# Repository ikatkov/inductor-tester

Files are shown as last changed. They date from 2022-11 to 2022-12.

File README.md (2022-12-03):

# (Power) Inductor saturation current tester

~60A max current. Power supply 5-25V.
Based on http://elm-chan.org/works/lchk/report.html

You will need an oscilloscope to take measurements.

# Theory

Once powered, the capacitor bank charges up. The circuit fires off a variable-width pulse into the MOSFET gate. MOSFET turns ON and short-circuits the inductor to the capacitor power bank. The current starts to rise linearly until the saturation point is reached. Once the inductor is saturated, it behaves like an ohmic piece of wire, and the current increases exponentially until the pulse is over, and the MOSFET is switched OFF. Saturation is a knee, not a sharp point. So you have some wiggle room in what current you designate as a "saturation current." Before the saturation point and including the "knee region," inductance will be higher than labeled. Once saturated sufficiently - inductance will drop.

This is how a regular plot should look like

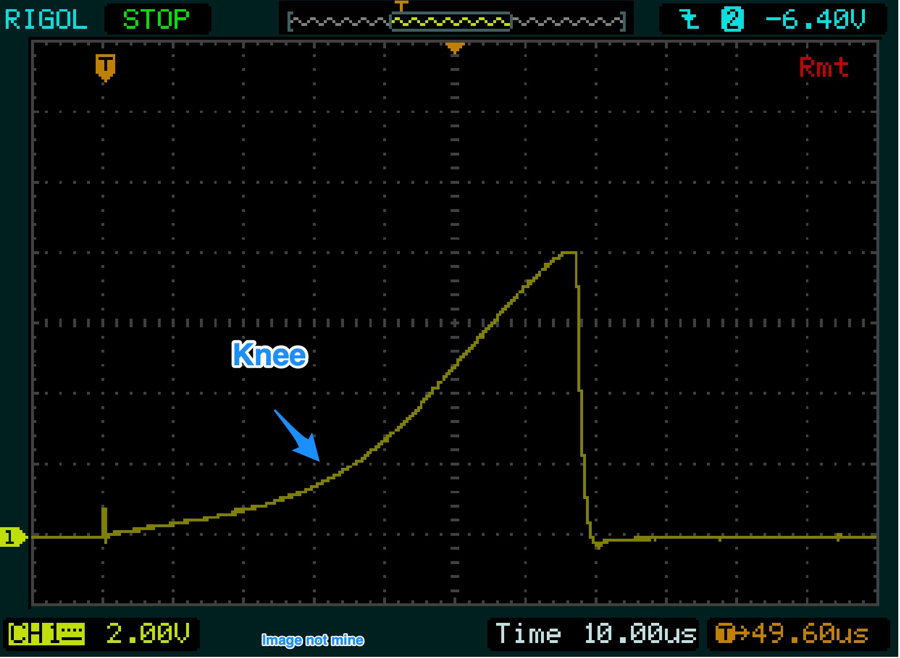
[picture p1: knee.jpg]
Knee


This is how oversaturation, should look like

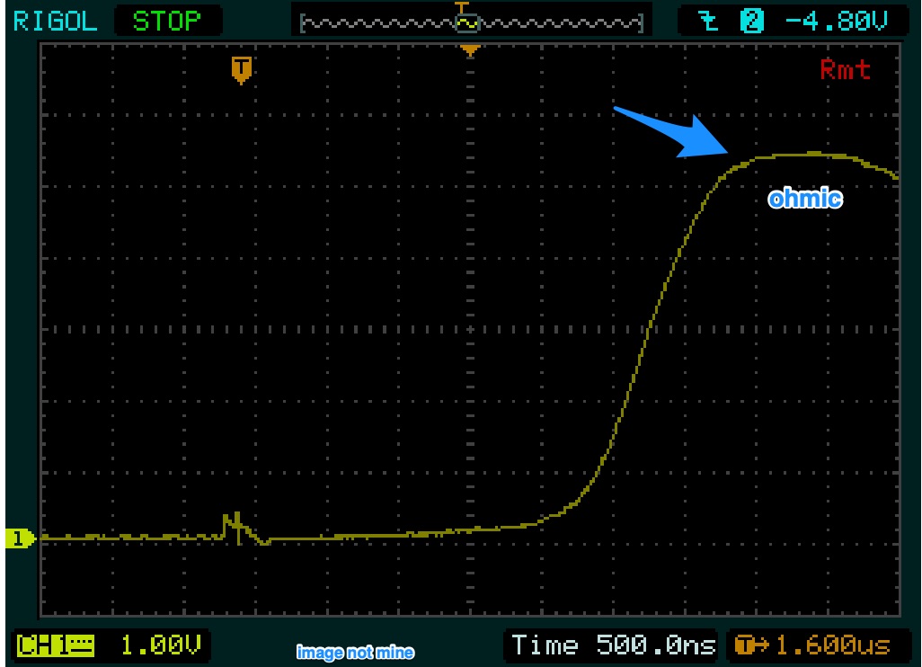
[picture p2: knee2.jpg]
Oversaturation


Commercial manufacturers pick the point where a power inductor loses 20-30% of its labeled inductance. One can safely operate inductors at x1.3-1.5 their knee point.

You take voltage drop measurements across 0.1 Ohm resistor, multiply by 10 and get current in Amps flowing through your inductor under test. `I = V*10`

You can also compute actual inductance be taking your supply voltage and dividing by the voltage slope. 
`L = Vs * Δt / ΔI`. 

# Practical operations

See "sort-of" instructions video https://www.youtube.com/watch?v=3Y_WcuIenSM
Notice that although their PCB is labeled 1us..50us. It's impossible to get a positive pulse width of less than 10uS with NE555. One can replace it with other astable timers ICs, but you need a separate MOSFET driving circuitry. NE555 raising and falling times ~350ns, with a max current of 200mA, which is not enough to quickly switch power MOSFETs ON/OFF. The MOSFET will be in its linear region for some time. Therefore the trigger pulse is set to ~50Hz, letting MOSFET cool down between pulses. Also, notice that the current sense shunt, capacitor bank ESR and traces resistance limits max current to ~56A.
You would want to rig some sort of replacable solder-pads on the top of the PCB, so you can finger-press small SMD inductors to it and solder large ones to take measurements. There are header holes for this.

* Unplug the power
* Turn the potentiometer all the way counterclockwise. Set the duration selector jumper to the shortest range. 
* Connect oscilloscope probes
* Plug the power
* Look at the oscilloscope
* Turn the potentiometer clockwise (increasing the pulse width) until you see the saturation knee
* If you still see a linear ramp, unplug, change the duration selector jumper to the next position, turn the potentiometer all the way counterclockwise and repeat
* Take measurements

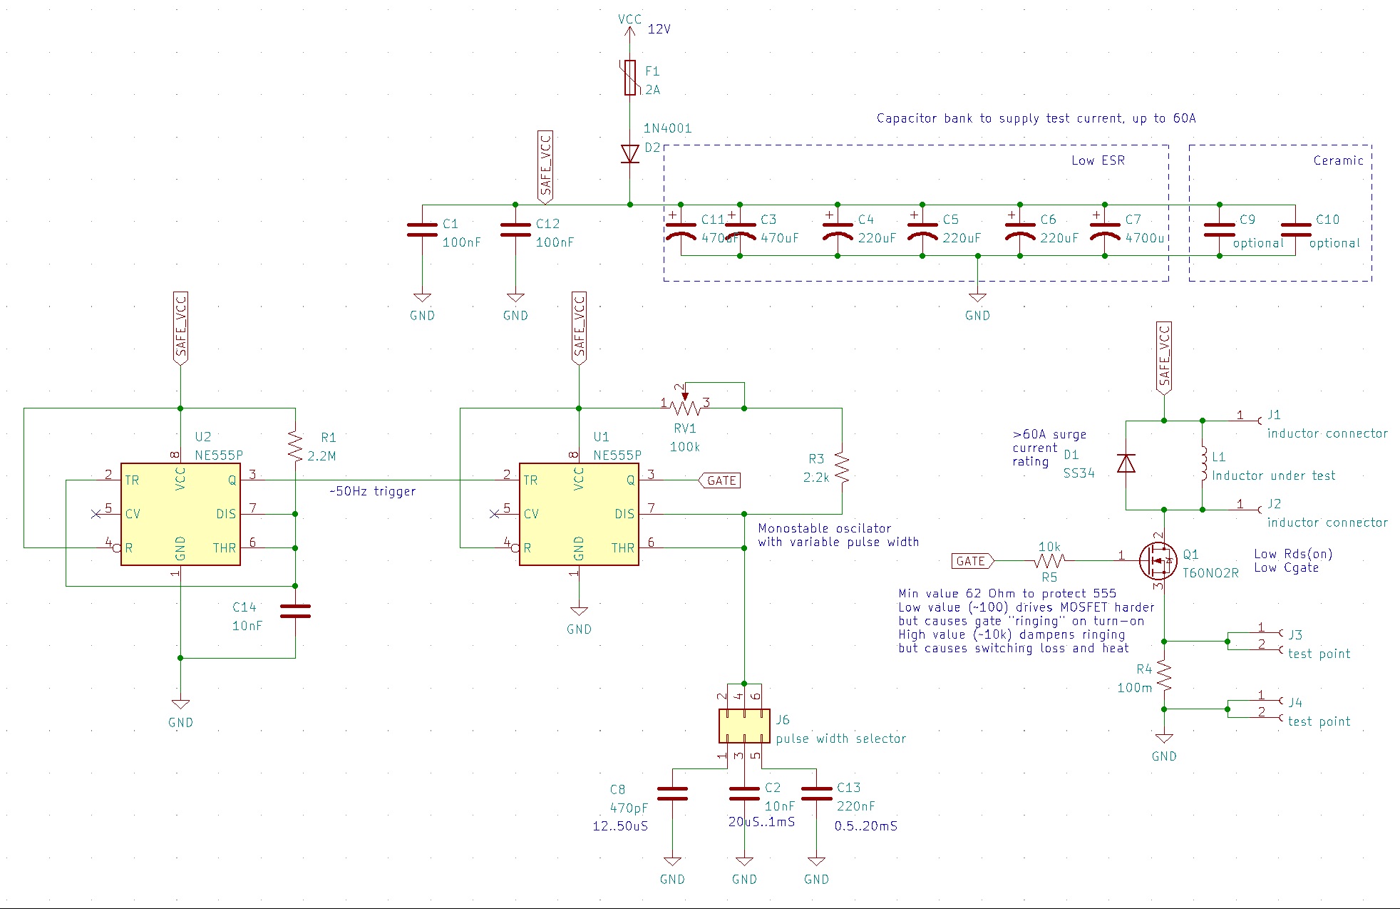
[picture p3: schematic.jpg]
Schematic


# Manufacturing

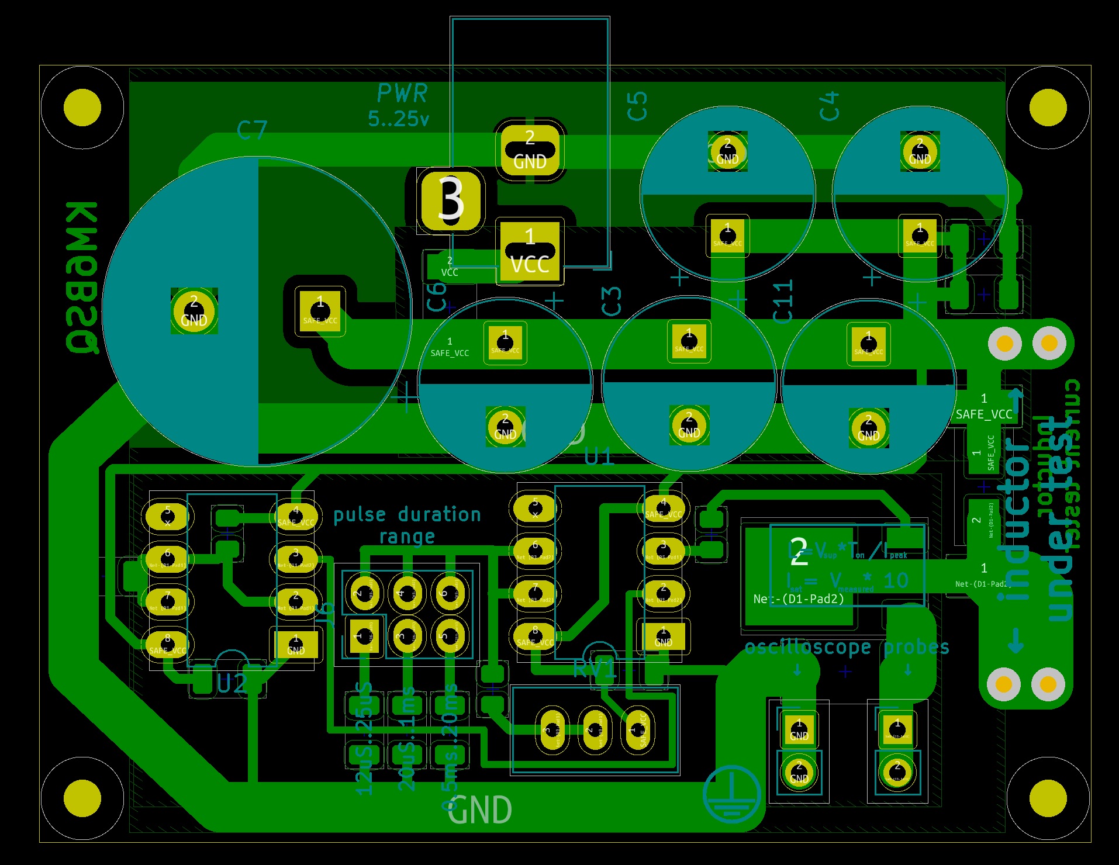
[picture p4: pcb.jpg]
PCB

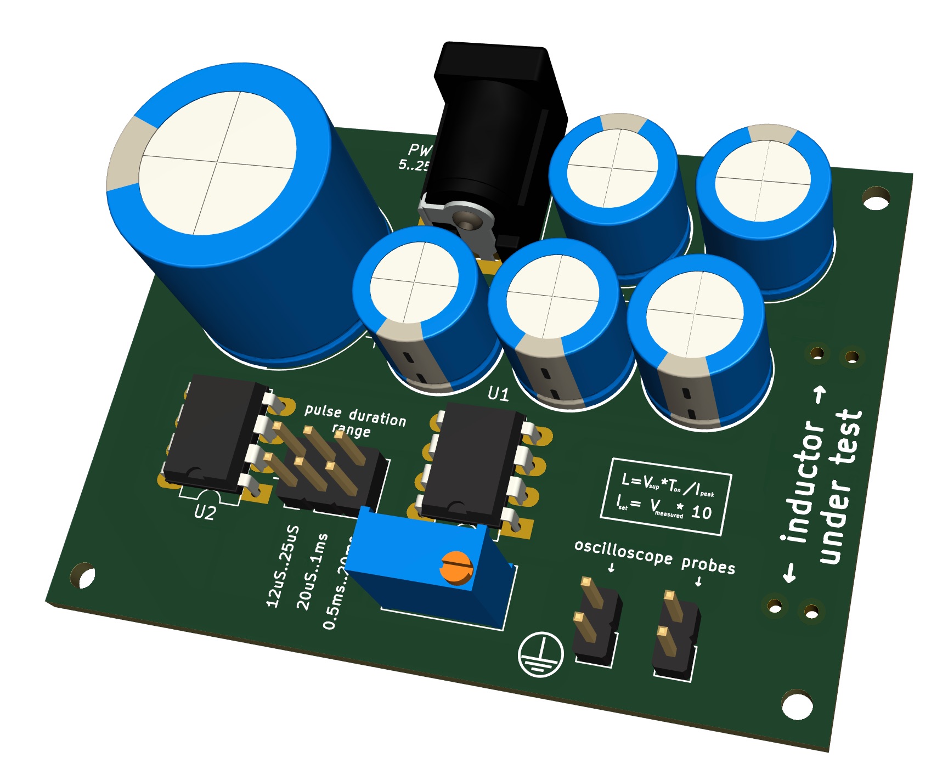
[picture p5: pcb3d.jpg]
Top view


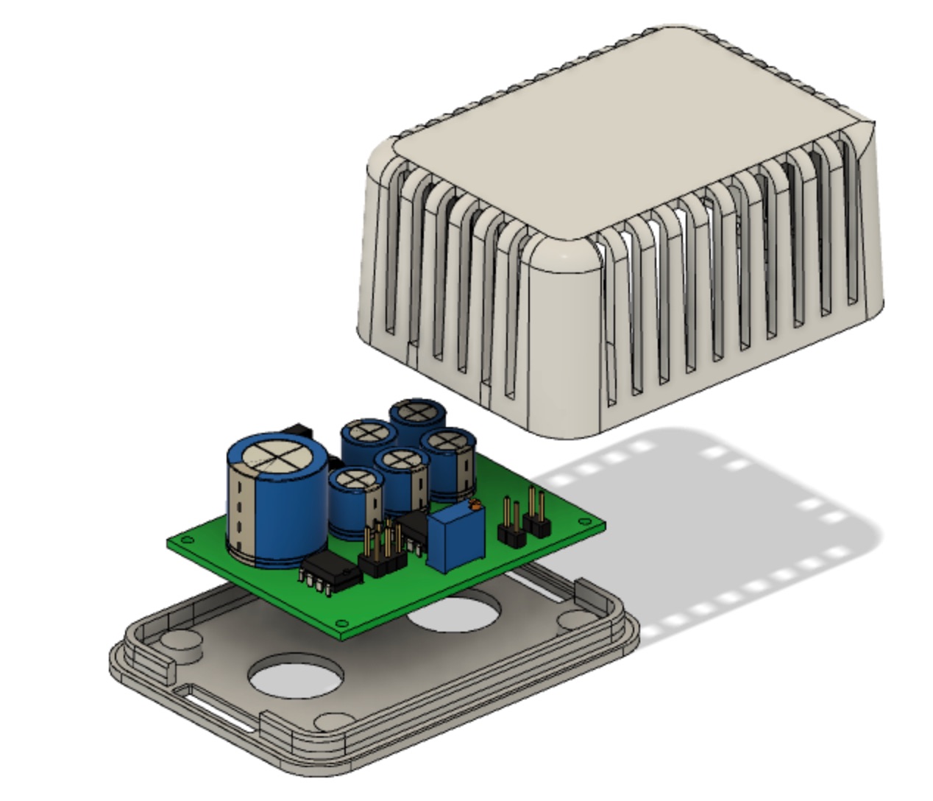
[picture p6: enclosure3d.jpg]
Enclosure


[PCB STEP model](main.step)

[Full STEP model](enclosure.step)

[Full Fusion360 model](enclosure.f3zki)

[PCB Thermal Heat Flow Analysis](heat.jpg)

# Future improvements

NE555 is a compromise for this project purpose, you need two of them to deliver a short pulse, but it can also source 200ma current by itself. An alternative design is to use a cheap MCU and a MOSFET driver. Same PCB footprint, but better timing (no need to mess around with jumpers) and higher currents to turn the MOSFET on and off. High gate current also means "ringing" 
on MOSFET turn on, which in turn manifests itself as current measurements ringing. For large inductors it is OK, for small (SMD) it might be hard to take measurements. With a better MCU one can even do automatic pulse control. This gets complex fast. 16 MHz Arduino is ~ 100uS per ADC sample. 

`For a 16 MHz Arduino the ADC clock is set to 16 MHz/128 = 125 KHz. Each conversion in AVR takes 13 ADC clocks so 125 KHz /13 = 9615 Hz.`

As soon as you consider a fast external ADC, you start worry about crystal clock-jitter, temperature drift and SPI speed.

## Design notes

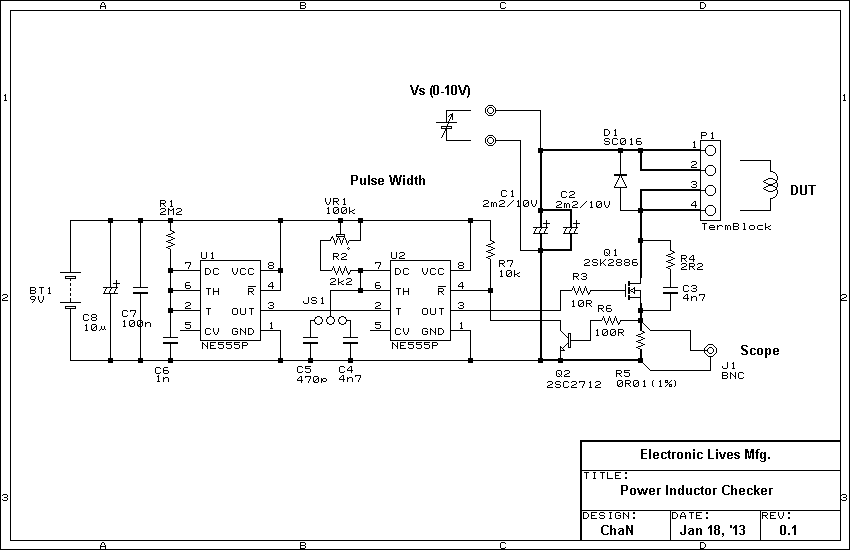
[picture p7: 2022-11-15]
original-lchk_schematic.png

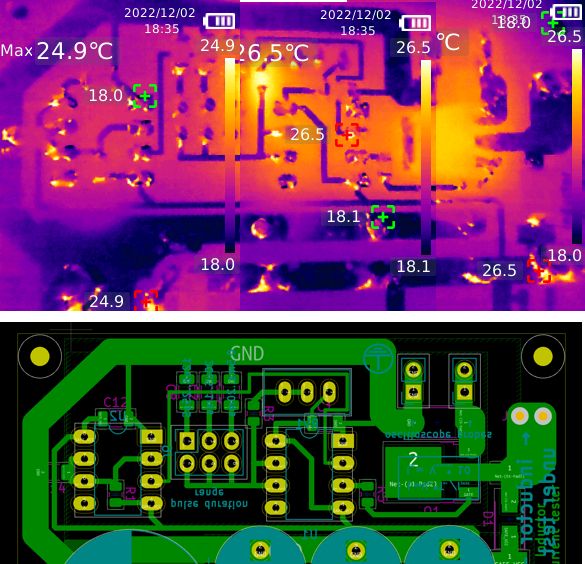
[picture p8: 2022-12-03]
heat.jpg

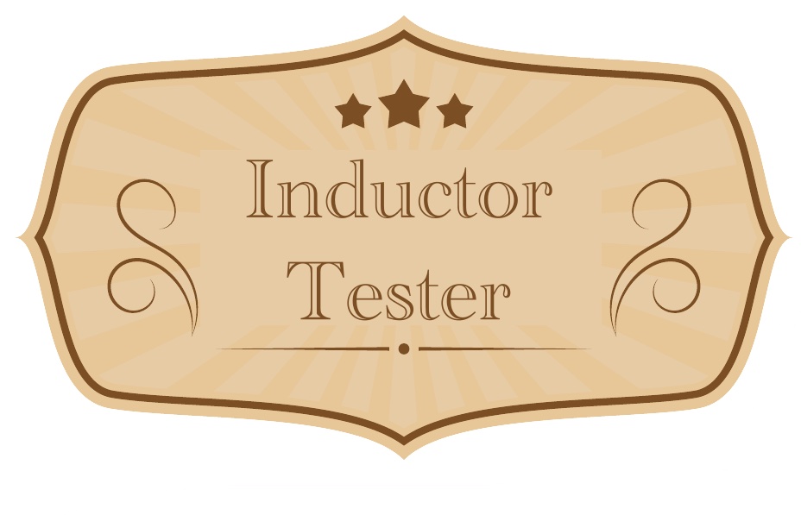
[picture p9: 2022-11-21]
label.jpg

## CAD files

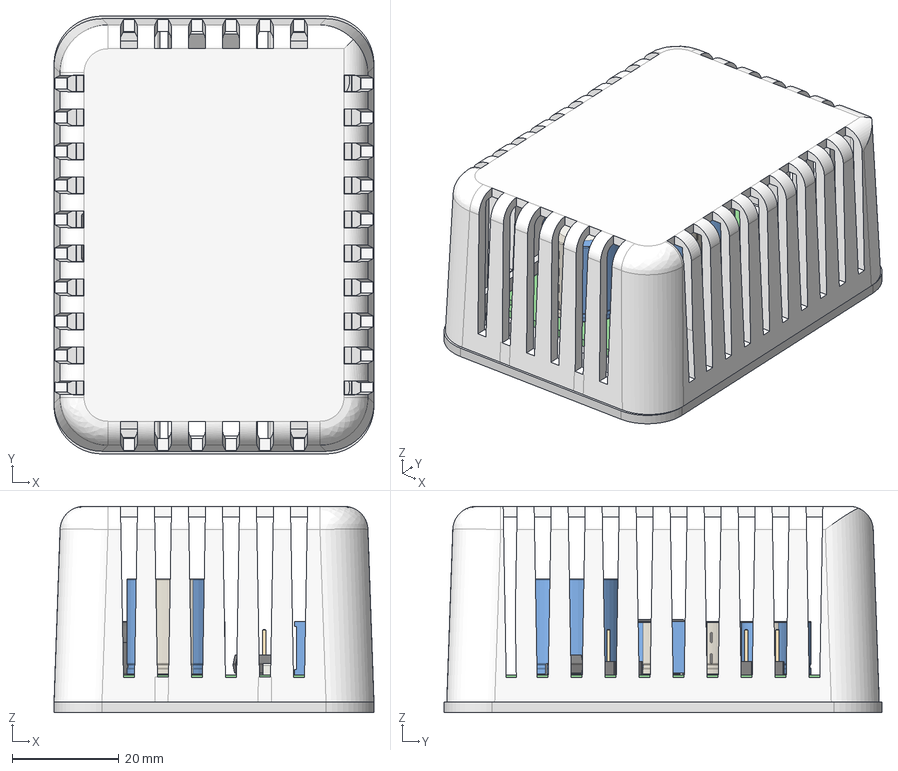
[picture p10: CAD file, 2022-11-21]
enclosure.step
60.0 x 82.1 x 38.7 mm
1551V1 BOT2
1551V1 TOP1
main PCB

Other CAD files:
enclosure.f3z

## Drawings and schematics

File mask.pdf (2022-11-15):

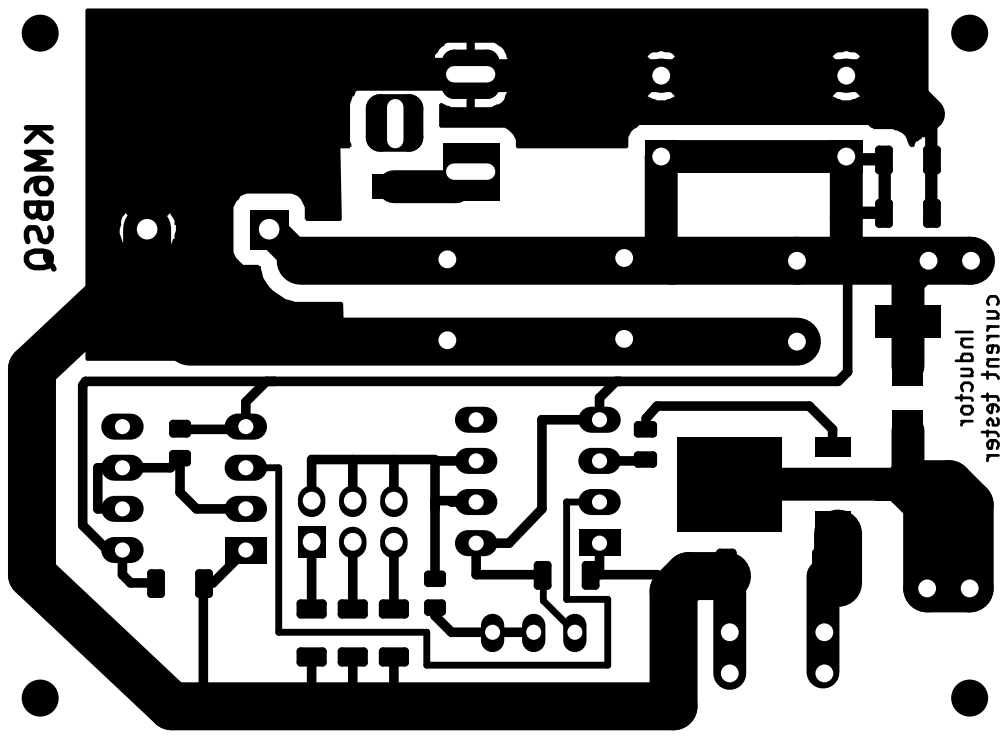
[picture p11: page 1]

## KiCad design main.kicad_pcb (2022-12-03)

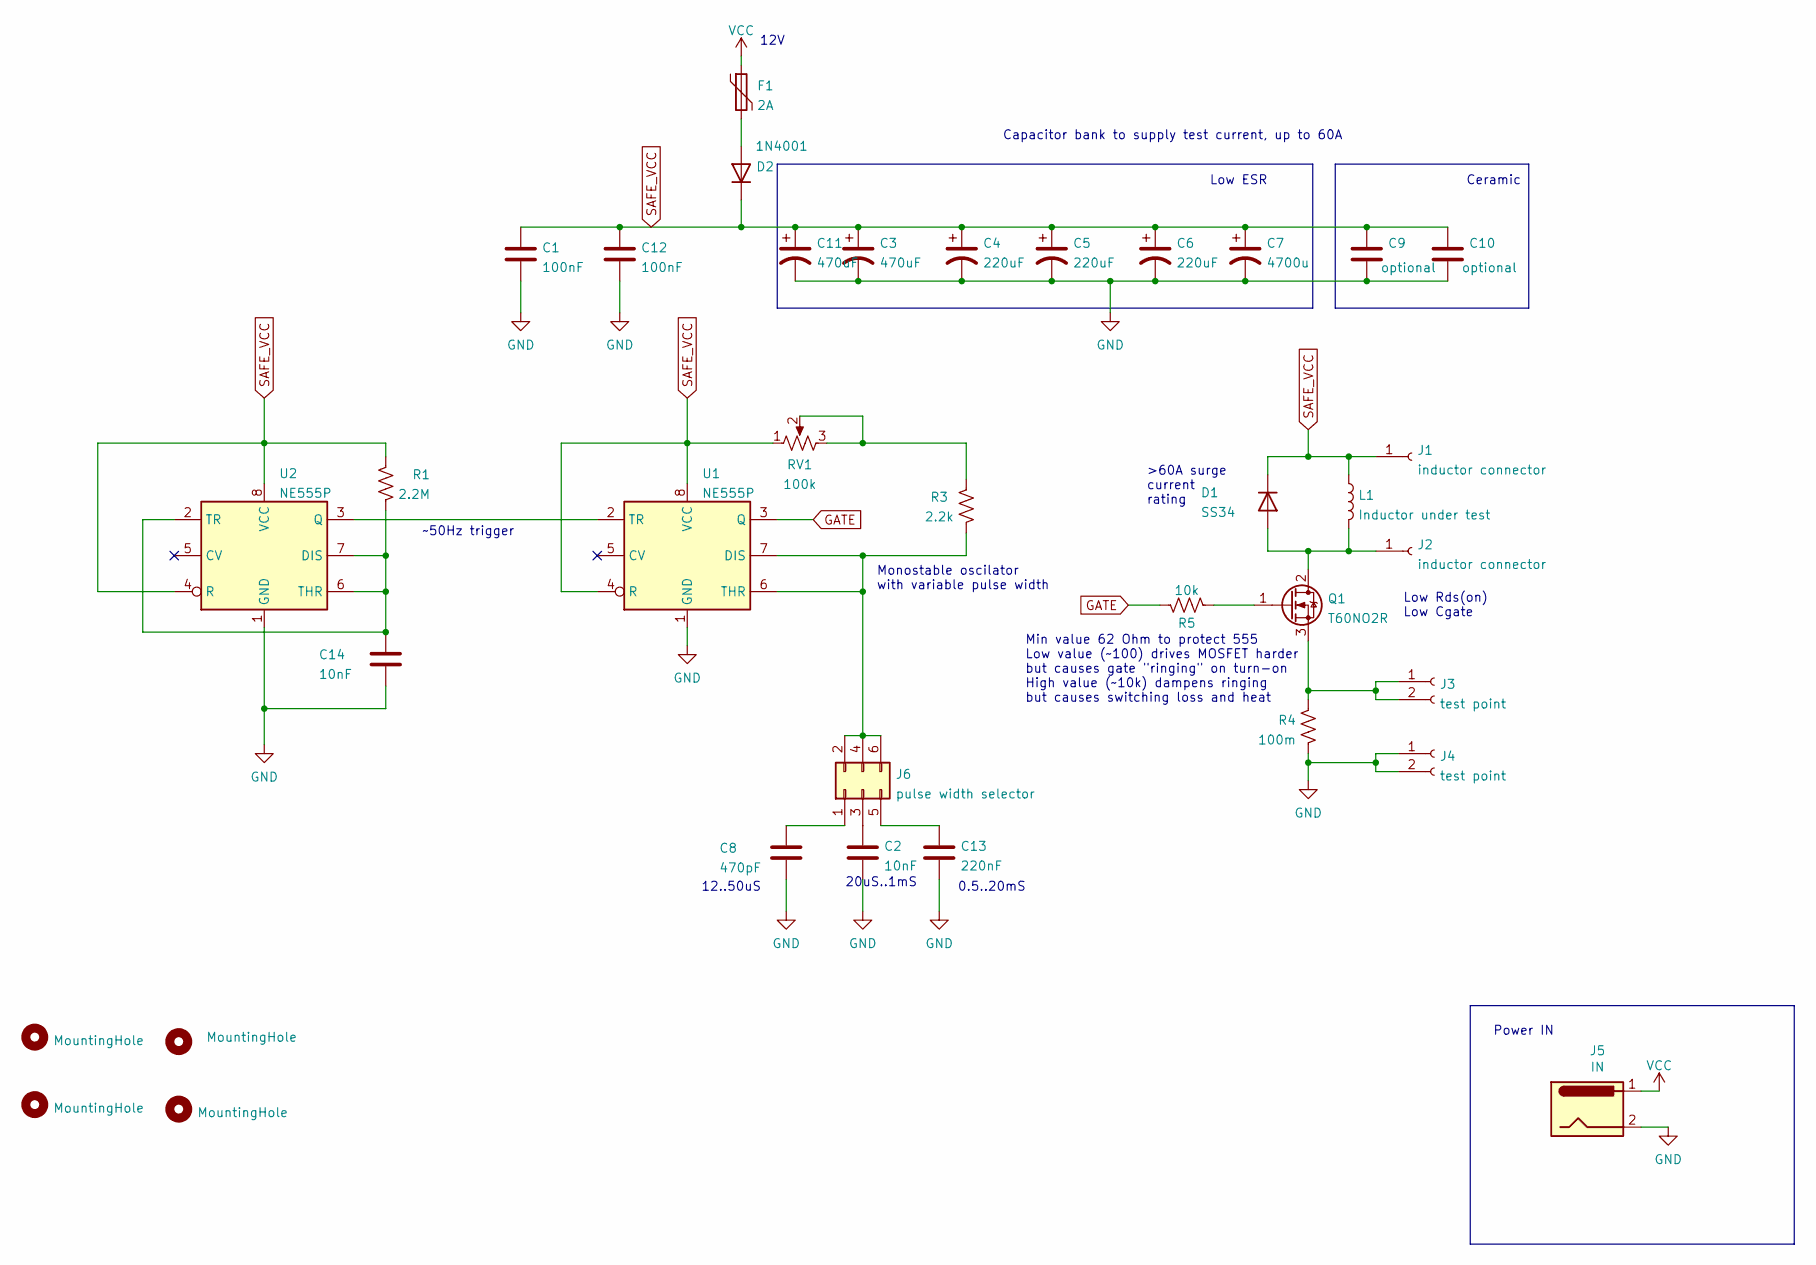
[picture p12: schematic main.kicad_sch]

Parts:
C1, C12: 100nF; C_1206_3216Metric
C2, C14: 10nF; C_1206_3216Metric
C3, C11: 470uF; CP_Radial_D10.0mm_P5.00mm
C4, C5, C6: 220uF; CP_Radial_D10.0mm_P5.00mm
C7: 4700u; CP_Radial_D18.0mm_P7.50mm
C8: 470pF; C_1206_3216Metric
C9, C10: optional; C_1206_3216Metric
C13: 220nF; C_1206_3216Metric
D1: SS34; D_SMA
D2: 1N4001; D_MELF
F1: 2A; R_MELF_MMB-0207
H1, H2, H3, H4: MountingHole; MountingHole_2.2mm_M2
J1, J2: inductor connector; SolderWirePad_1x01_SMD_2x4mm
J3, J4: test point; PinHeader_1x02_P2.54mm_Vertical
J5: IN; BarrelJack_Horizontal
J6: pulse width selector; PinHeader_2x03_P2.54mm_Vertical
L1: Inductor under test
Q1: T60NO2R; TO-252-2
R1: 2.2M; R_0805_2012Metric
R3: 2.2k; R_0805_2012Metric
R4: 100m; R_2512_6332Metric
R5: 10k; R_0805_2012Metric
RV1: 100k; Potentiometer_Bourns_3296W_Vertical
U1, U2: NE555P; DIP-8_W7.62mm

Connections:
GATE: Q1.1 (G), R5.2
GND: C1.2, C2.2, C3.2, C4.2, C5.2, C6.2, C7.2, C8.2, C9.2, C10.2, C11.2, C12.2, C13.2, C14.2, J4.1, J4.2, J5.2, R4.2, U1.1 (GND), U2.1 (GND)
unnamed: C2.1, J6.3
unnamed: C8.1, J6.1
unnamed: C13.1, J6.5
unnamed: C14.1, R1.1, U2.2 (TR), U2.6 (THR), U2.7 (DIS)
unnamed: D1.2 (A), J2.1, L1.2, Q1.2 (D)
unnamed: D2.2 (A), F1.2
unnamed: J3.1, J3.2, Q1.3 (S), R4.1
unnamed: J6.2, J6.4, J6.6, R3.2, U1.6 (THR), U1.7 (DIS)
unnamed: R3.1, RV1.2, RV1.3
unnamed: R5.1, U1.3 (Q)
unnamed: U1.2 (TR), U2.3 (Q)
SAFE_VCC: C1.1, C3.1, C4.1, C5.1, C6.1, C7.1, C9.1, C10.1, C11.1, C12.1, D1.1 (K), D2.1 (K), J1.1, L1.1, R1.2, RV1.1, U1.4 (R), U1.8 (VCC), U2.4 (R), U2.8 (VCC)
VCC: F1.1, J5.1

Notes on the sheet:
Low ESR
Low Rds(on) Low Cgate
0.5..20mS
Power IN
12..50uS
20uS..1mS
12V
Capacitor bank to supply test current, up to 60A
>60A surge current rating
Ceramic
Monostable oscilator with variable pulse width
~50Hz trigger
Min value 62 Ohm to protect 555 Low value (~100) drives MOSFET harder but causes gate "ringing" on turn-on High value (~10k) dampens ringing but causes switching loss and heat

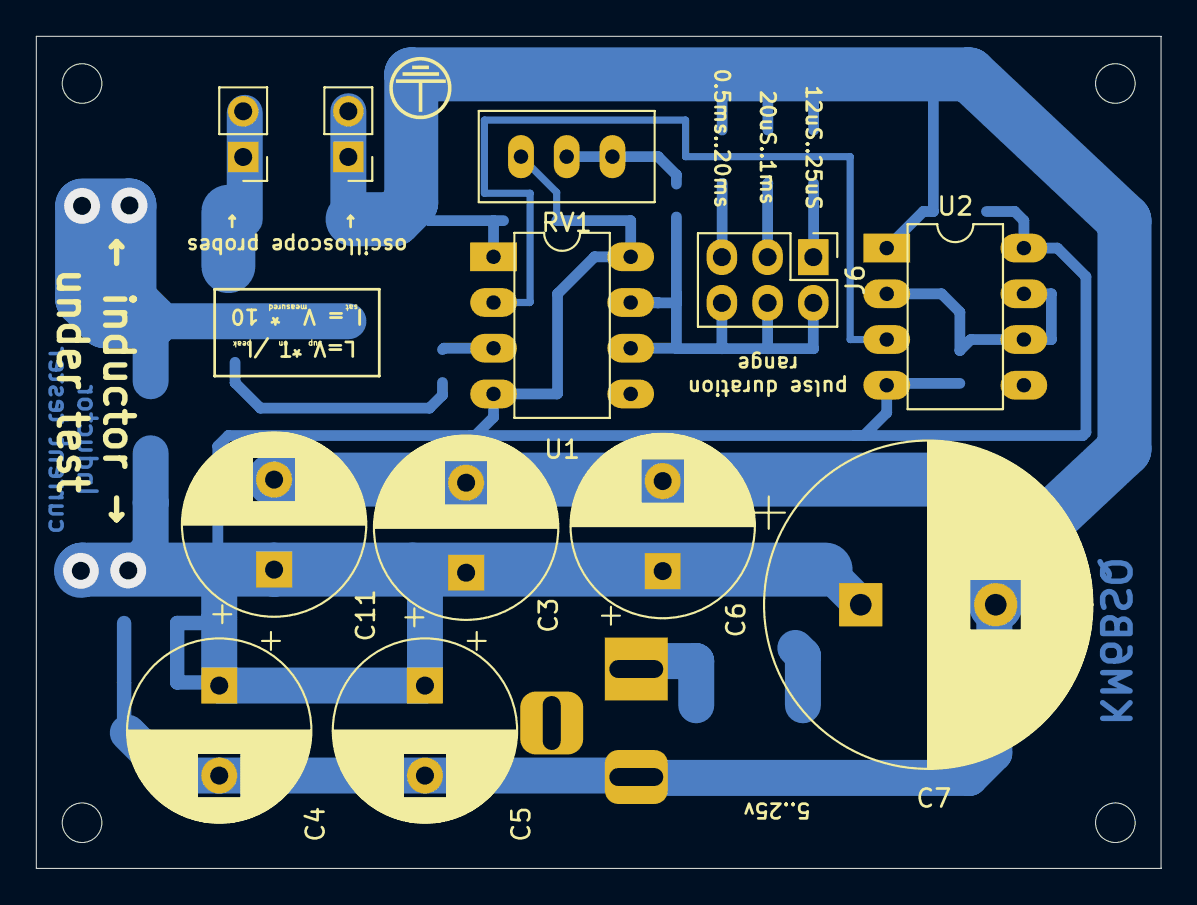
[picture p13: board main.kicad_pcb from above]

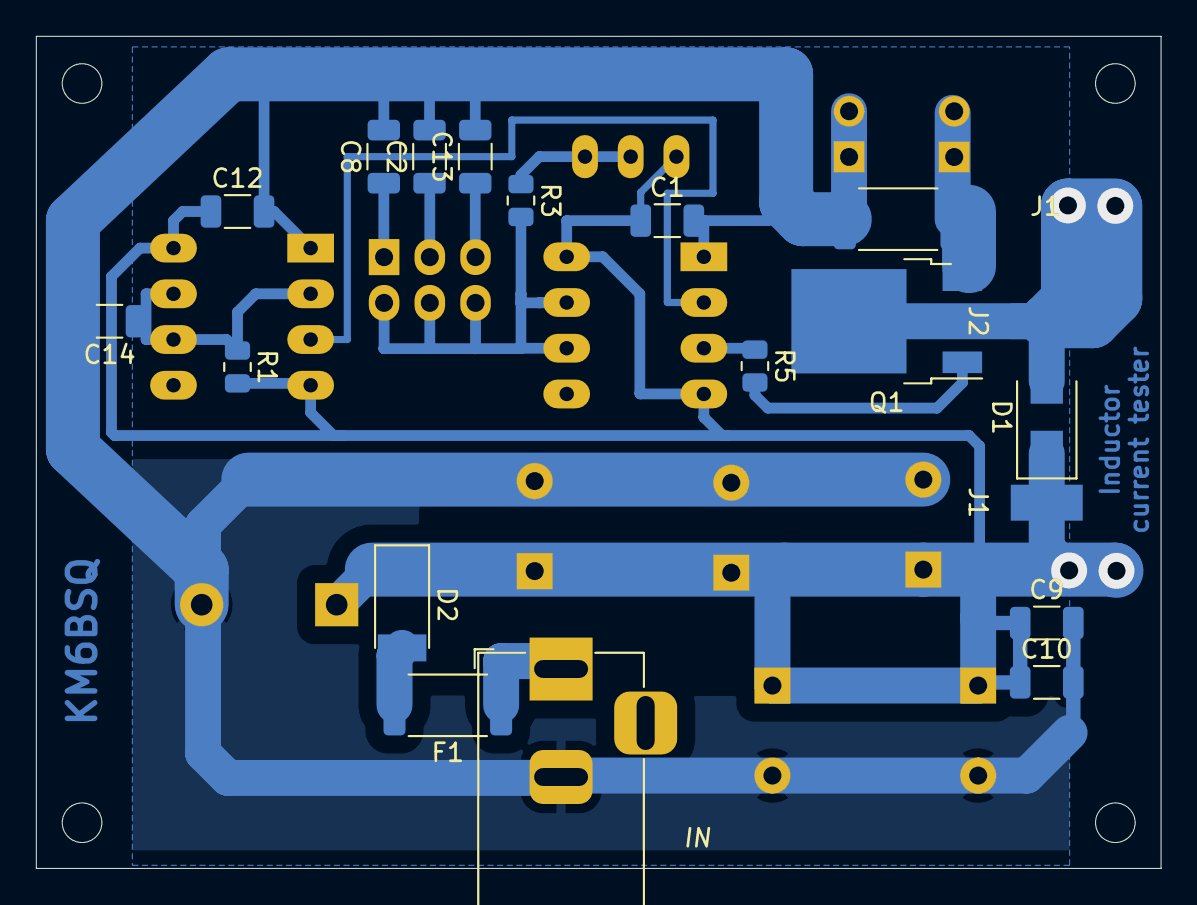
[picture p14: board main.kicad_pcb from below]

Board: 4 copper layers, 62.5 x 46.2 mm, 35 parts (19 on the bottom side), 15 nets.

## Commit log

2022-11-15 solder pad explanation
2022-11-21 more details
    [enclosure.f3z, enclosure.step, main.kicad_pcb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]
2022-11-21 update diode description
2022-12-03 Changed gate resistor Add heat map
    [main.kicad_pcb, main.kicad_sch]
